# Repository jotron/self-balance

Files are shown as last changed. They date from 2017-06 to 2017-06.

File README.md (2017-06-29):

# Selbst-Balancierender Roboter

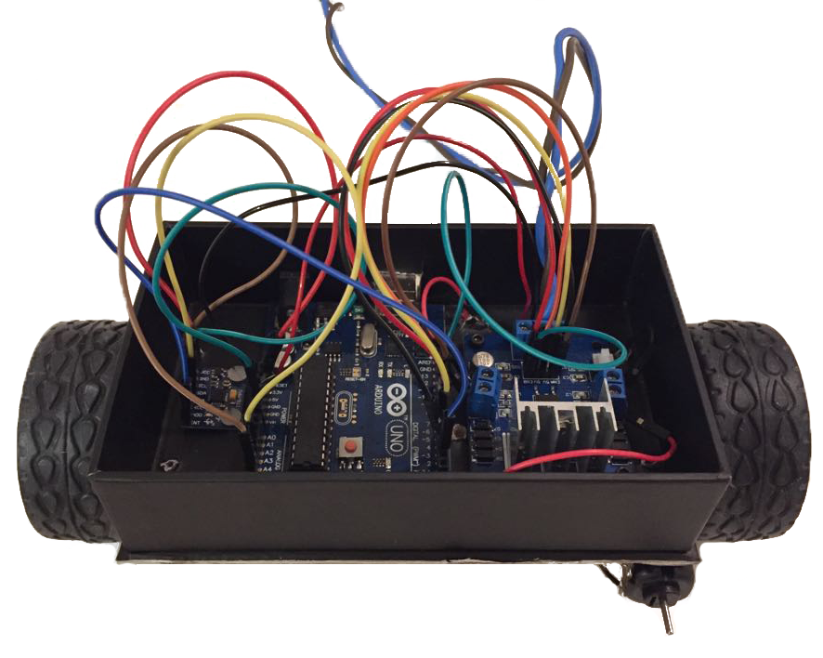
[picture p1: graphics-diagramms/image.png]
Robot


### Ziel

Ziel ist es einen Roboter mit 2-Rädern zu bauen, der von selbst gerade stehen kann in dem er sich ausbalanciert.

Mit einem Sensor soll der Roboter die Abneigung zur Senkrecht-Achse messen. Daraus folgend soll er die Motoren in die richtige Richtung stark genug antreiben.

balancing

### Bauteile

- Arduino Uno
- L298N Motor Driver Board Dual H-Bridge ([OEM](http://www.play-zone.ch/de/l298n-motor-driver-board-schrittmotor-treiber-modul-1550.html))
- MPU-6050 Gyroskop + Accelerometer ([Invensense](http://www.play-zone.ch/de/mpu-6050-accelerometer-gyro.html))
- 2 DC-Motoren (mit Getriebe)

### Schaltskizze

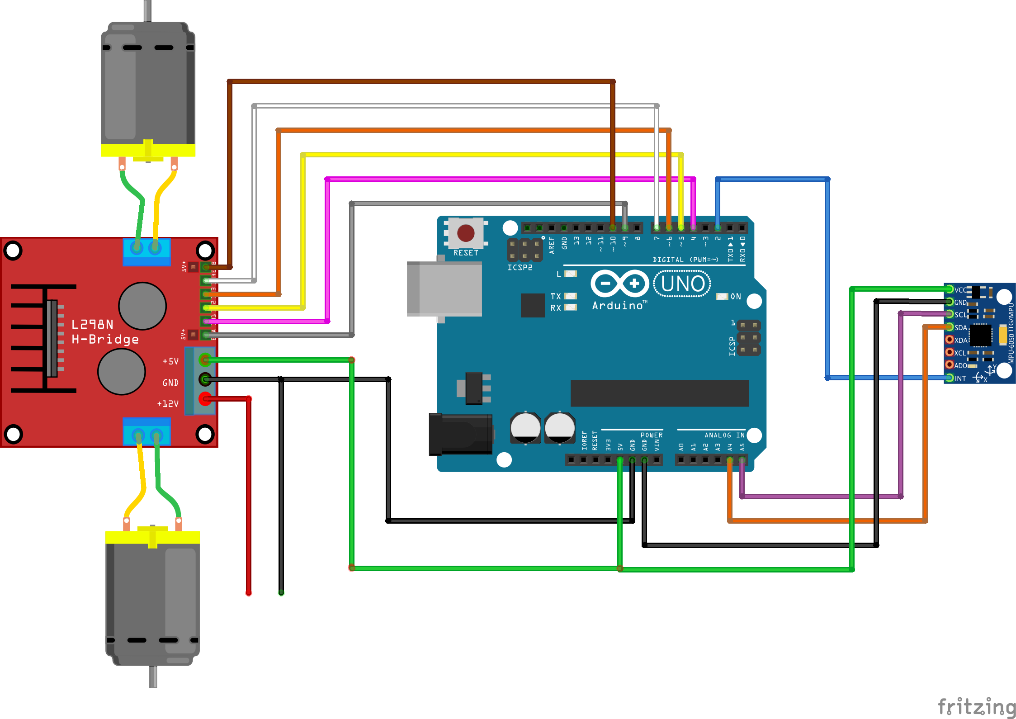
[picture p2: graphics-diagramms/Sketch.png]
Sketch


### Libraries 

- [PID](https://github.com/br3ttb/Arduino-PID-Library/)
- [I2Cdev](https://github.com/jrowberg/i2cdevlib)
- [MPU6050](https://github.com/jrowberg/i2cdevlib/tree/master/Arduino/MPU6050)
- Wire

### Arbeitsvorgang

1. [MPU-6050 Sensordaten ablesen](individual_files/mpu6050/MPU6050.md)
2. [Motoren ansteuern](individual_files/l298n/l298n.md)
3. [Steuerung von Motoren in Abhängigkeit der Neigung (PID)](individual_files/PID/PID.md)

### Fazit

[Kleines Video](graphics-diagramms/IMG_3839.mp4)

Das Projekt hatte sehr hohe Ansprüche. Schlussendlich sind wir mit der Realisation unseres Projekts zufrieden. Der Roboter balanciert zwar nicht stabil aber theoretisch haben wir alles richtig gemacht. Wir wissen noch nicht ob der Fehler technischer Natur ist oder aufgrund der Steuerung. 
Einerseits könnte das Problem daran liegen, dass unsere Motoren zu langsam reagieren, da bei jedem Richtungswechsel die Trägheit überwunden werden muss.  
Andernseits  könnte es daran liegen, dass wir einfach noch nicht die richtigen Parameter für den PID-Controller gefunden haben.
Schlussendlich ist es auch möglich, dass der niedrige Aufbau das Problem ist. Die Motoren müssen nämlich innerhalb von wenigen Milisekunden unter den fallenden Überbau fahren, was vielleicht zu schnell ist.

Das Schöne an diesem Projekt für uns ist eigentlich die lehrreiche Erfahrung. Wir haben sehr viel gelernt über einzelne Bauteile bis zu wie man ein solches Elektronik-Projekt angeht und wo eventuell Schwierigkeiten auftreten können.

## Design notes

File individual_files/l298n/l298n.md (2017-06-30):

## L298N H-Brücke

Der zweite Schritt bestand darin die Motoren mit der H-Brücke zu verkabeln und diese zur externen Stomquelle und zum Arduino. Das Wissen dazu haben wir aus diesen drei Tutorials erlernt: [Dronebotworkshop](http://dronebotworkshop.com/dc-motors-l298n-h-bridge/), [QQtrading](http://qqtrading.com.my/stepper-motor-driver-module-L298N), [Robotoid](http://www.robotoid.com/appnotes/circuits-l298-hbridge.html).

### Funktionsweise

#### Einfache H-Brücke

Prinzipschaltbild Motorsteuerung: H-Bridge mit vier Schaltern, der Motor vervollständigt das 'H'

Man kann sich eine H-Brücke der Einfachheit als 4 Schalter vorstellen. Werden in der Abbildung *Schalter 1* und *Schalter 4* aktiviert, dreht der Motor in eine Richtung. Werden hingegen *Schalter 3* und *Schalter 2* aktiviert drehr der Motor logischerweise in die andere Richtung. 
Auf unserem Chip besteht die H-Brücke allerdings nicht aus Schaltern sondern Transitoren.
Wird Spannung auf dem ersten und vierten Transistor aufgelegt fliesst der Strom und der Motor dreht. Analog dreht der Motor in die andere Richtung falls Transistor zwei und drei unter Spannung stehen.



#### L298N Doppelte H-Brücke

Der Chip den wir benutzen ist allerdings noch komplexer. Er besteht nämlich aus zwei H-Brücken und einem 5V Regulator. 
Im obereren Teil der Grafik sind alle Pins  sowie ihre Funktion gekennzeichnet in einer Schaltskizze.
Im unteren Teil der Grafik sieht man was sonst noch alles auf dem Chip ist. Man erkennt zum Beispiel im Rechten Teil die Dioden und links Oben den 5V-Regulator.



Die Motoren lassen sich je über 3 Pins ansteuern. Für den Motor A sind es die Pins IN1, IN2 sowie EnableA. Für den Motor B die pins IN3, IN4 und EnableB. Die IN Pins kontrollieren die Richtung des Stroms und somit die Richtung der Motoren.

| IN1  | IN2  | A Motorbewegung |
| ---- | ---- | --- |
| LOW  | LOW  | nichts |
| HIGH | LOW  | vorwärts |
| LOW  | HIGH | rückwärts |
| HIGH | HIGH | festhalten |

Die *Enable* Pins kontrollieren die Spannung über PWM und somit die Geschwindigkeit des jeweiligen Motors.

### Stromzufuhr

Eine Schwierigkeit bestand darin wie man den Strom zuführen sollte. Wir wollten nämlich auf zwei verschiedene Stromquellen verzichten. Schlussendlich haben wir uns entschieden den Arduino über die H-Brücke zu füttern und diese über ein 12V Netzkabel. Die H-Brücke besitzt nämlich einen 5V-Regulator. Das einzige Risiko dabei war, dass die Motoren eventuell zu viel elektrischen Lärm machen würden. Dies hat sich aber nicht bestätigt.

### Mini-Schaltskizze

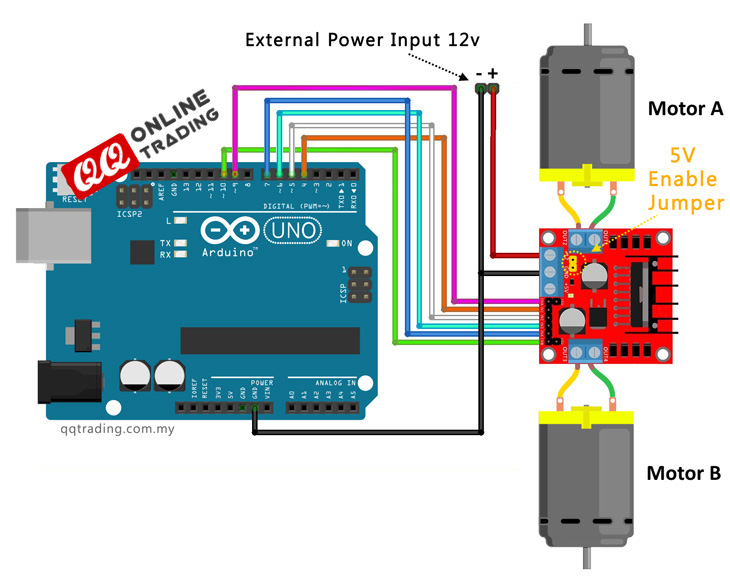
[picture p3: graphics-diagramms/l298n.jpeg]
l298n


### Code

```C
// PINS definieren Motor A
int IN1 = 4;
int IN2 = 5;
int speedPinA = 9; // PWM

// PINS definieren Motor B
int IN3 = 6;
int IN4 = 7;
int speedPinB = 10; // PWM

void setup()
{
 // Ausgabe PINS
 pinMode(IN1, OUTPUT);
 pinMode(IN2, OUTPUT);
 pinMode(IN3, OUTPUT);
 pinMode(IN4, OUTPUT);
 pinMode(speedPinA,OUTPUT);
 pinMode(speedPinB,OUTPUT);
}

void loop() {
  
 analogWrite(speedPinA, 50); // Geschwindigkeit einstellen 0-255
 analogWrite(speedPinB, 50); 

 // Motor A forwaerts
 digitalWrite(IN1, HIGH);
 digitalWrite(IN2, LOW);
 delay(2000);
 
 // Motor A rueckwaerts
 // digitalWrite(IN1, LOW);
 // digitalWrite(IN2, HIGH);
 // delay(2000);

 // Motor A deaktivieren
 // digitalWrite(IN1, LOW);
 // digitalWrite(IN2, LOW);
 // delay(2000);

 // Motor B forwaerts
 digitalWrite(IN3, HIGH);
 digitalWrite(IN4, LOW);
 delay(2000);
 
 // Motor B rueckwaerts
 // digitalWrite(IN3, LOW);
 // digitalWrite(IN4, HIGH);
 // delay(2000);

 // Motor B deaktivieren
 // digitalWrite(IN3, LOW);
 // digitalWrite(IN4, LOW);
 // delay(2000);
}
```

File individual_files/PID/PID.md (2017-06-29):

## Steuerung in Abhängigkeit der Neigung mittels PID

Es musste ein System entwickelt werden welches je nach Neigung des Roboters, die Motoren richtig ansteuerte. Dies erwies sich als ausserordentlich schwierig. Die intuitive Version einfach je nach Neigung mit voller Kraft in die richtige Richtung anzutreiben funktioniert nicht.
Wir haben darum eine Bibliothek gefunden die uns diese Aufgabe erleichtert: die [PID Bibliothek](https://playground.arduino.cc/Code/PIDLibrary).

Wikipedia: "Der [PID-Regler](https://de.wikipedia.org/wiki/Regler#PID-Regler) (proportional–integral–derivative controller) besteht aus den Anteilen des Proportionalen Gliedes, des Integral-Gliedes und des Derivativ-Gliedes." Die Bibliothek vergleicht den Input-Wert mit dem gewünschten Output-Wert und versucht den Stellwert optimal zu erreichen.
Man muss dem Regler lediglich einen Input vorschreiben und das gewünschte Resultat einstellen. Der Regler berechnet dann den Weg der minimalen Abweichung. Wie genau die Formel lautet die der Regler verwendet besprechen wir in dieser Arbeit nicht. Der Wikipedia Artikel wird nämlich ziemlich schnell recht komplex.

Der P-Wert steuert dabei wie stark der Roboter schwankt. Der I-Wert vermeidet "Overshoot" und treibt die Motoren gleichmässiger an. Der D-Wert korrigiert eventuelle Fehler.

### Code

Die Anpassungsparameter sind Kp, Ki & Kd.

```c
#include <PID_v1.h>

//Variablen und Parameter definieren
double pid_output = 0.0;
double pid_input = 255; // Neigung gegenüber Senkrecht-Achse
double setpoint = 255;
double Kp = 10;   //Schwankstärke
double Kd = 2; // beruhigen
double Ki = 0; // beruhigen

//PID aufstellen mit den Einstellungskonstanten und den INPUT/OUTPUT Variablen
PID pid(&pid_input, &pid_output, &setpoint, Kp, Ki, Kd, DIRECT);

void setup()
{
  //anschalten
  pid.SetMode(AUTOMATIC);
  
  //Alle 10ms neuberechnen
  pid.SetSampleTime(10);
}

void loop()
{
  //PID kontroller rechnen lassen, nur wenn 10ms vergangen sind, wird etwas passieren
  pid.Compute();
}
```

Der Regler schreibt automatisch in den pid_output. In unserem Programm bezeichnetein pid_input von 255 eine Neigung von 0° gegenüber der Senkrechtachse und ein pid_input von 0 einen +-90° Winkel. Die Richtung der Motoren wird separat manuell berechnet in abhängigkeit der Neigung.

Um auf die richtigen Konstanten zu kommen, benutzen wir die Ziegler-Nichols Methode:

1. Alle Werte auf 0 stellen
2. P so lang erhöhen bis der Roboter stark hin und her schwankt.
3. I so lang erhöhen bis der Roboter stabil steht
4. D experimentieren

Was uns gestört hat an der PID-Bibiothek ist, dass sie nicht selber die Richtung der Motoren kontrollieren kann. Wenn wir der Bibliothek nämlich Inputs von -255(rückwärts) bis +255(vorwärts) geben und der Roboter stabil steht, wird die Bibliothek den tiefsten Wert ausgeben -255 obwohl sie eigentlich 0 ausgeben sollte. 
An die richtigen Werte zu kommen ist ebenfalls sehr schwierig. Wir sind bis zum Abgabetermin noch auf keine funktionierenden Werte gekommen.

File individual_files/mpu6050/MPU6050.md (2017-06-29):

## MPU-6050

### Funktionsweise

#### Accelerometer
Der Accelerometer funktioniert auf Basis der [Piezoelektrizität](https://de.wikipedia.org/wiki/Piezoelektrizit%C3%A4t). Man kann sich eine kleine Box mit einer Kugel im inneren vorstellen. Jedes Mal wenn die Box in eine Richtung beschleuingt wird, stösst die Kugel an eine der 6 Wände aus Kristall. Bei diesem Stoss entsteht elektrische Ladung die gemessen werden kann.

Das Accelerometer misst also immer die totale wirkende Beschleunigung/Kraft.

Accelerometer

#### Gyroskop
Das Gyroskop funktioniert ähnlich dem Accelerometer mit Piezokristallen. Zusätzlich wird das Coriolis-Prinzip ausgenützt. Man kann sich eine Gabel-artige Struktur vorstellen die konstant hin und her schwingt. Wenn nun Bewegung Auftritt wirkt eine Kraft auf ein Ende der Gabel, was mit den Piezokristallen wiederum gemessen werden kann.
Das Gyroskop misst also nicht direkt die Neigung sondern nur die Änderung.

Gyroskop

### I2C

Als Kommunikationsprotokol mit dem Sensor vewenden wir *Inter-integrated Circuit*. Das Protokoll benötift zwei Verbindungen: *SCL* und *SDA*. *SCL* ist das Clock-Signal. Es ermörglicht synchronisierte Kommunikation.
*SDA* ist das Daten-Signal. Über dieses Kabel werden die Daten ausgetauscht.

Genauer als das haben wir das Protokoll nicht analysiert. Das ganze scheint recht komplex zu sein um es wirklich zu verstehen.

### Zusammenbau und Code

Als aller erstes haben wir den Sensor mit dem Arduino verbunden und die rohen Daten abgelesen. 

Fig (4) : CONNECTION DIAGRAM (tutorial 1) 

```c
int16_t ax, ay, az;
int16_t gx, gy, gz;

void setup() {
    // join I2C bus (I2Cdev library doesn't do this automatically)
    #if I2CDEV_IMPLEMENTATION == I2CDEV_ARDUINO_WIRE
        Wire.begin();
    #elif I2CDEV_IMPLEMENTATION == I2CDEV_BUILTIN_FASTWIRE
        Fastwire::setup(400, true);
    #endif

    // initialize serial communication
    // (38400 chosen because it works as well at 8MHz as it does at 16MHz, but
    // it's really up to you depending on your project)
    Serial.begin(9600);

    // initialize device
    Serial.println("Initializing I2C devices...");
    accelgyro.initialize();

    // verify connection
    Serial.println("Testing device connections...");
    Serial.println(accelgyro.testConnection() ? "MPU6050 connection successful" : "MPU6050 	   connection failed");

    accelgyro.setXGyroOffset(220);
    accelgyro.setYGyroOffset(76);
    accelgyro.setZGyroOffset(-85);
}

void loop() {
	accelgyro.getMotion6(&ax, &ay, &az, &gx, &gy, &gz);
}
```

Dabei haben uns die [offzielle Arduino Dokumentation](https://playground.arduino.cc/Main/MPU-6050), [ein Tutorial](https://create.arduino.cc/projecthub/Aritro/getting-started-with-imu-6-dof-motion-sensor-96e066) sowie die Beispiele in der Bibiliothek geholfen. Den vollständigen, funktionierenden Beispiel-Code findet man [hier](https://raw.githubusercontent.com/jrowberg/i2cdevlib/master/Arduino/MPU6050/examples/MPU6050_raw/MPU6050_raw.ino).

Um aus den rohen Daten die Neigung zu bekommenhaben wir anfänglich die rohen Accelerometer und Gyroskop-Werte mittels [Komplementären-Filter](https://bayesianadventures.wordpress.com/2013/10/20/gyroscopes-accelerometers-and-the-complementary-filter/) kombiniert um den Winkel zur Senkrechtachse zu bekommen. 

```c
void loop() {
    // read raw accel/gyro measurements from device
    accelgyro.getMotion6(&ax, &ay, &az, &gx, &gy, &gz);

    // Convert accelerometer raw values to degrees
    accXangle = (atan2(ay, az) + PI) * RAD_TO_DEG;
    accYangle = (atan2(ax, az) + PI) * RAD_TO_DEG;

    //Gyroskop in grad/sec umwandeln
    gx_correct = gx / 131;
    gy_correct = gy / 131;
    gz_correct = gz / 131;

    // Komplämentärer Filter
    compAngleX = (0.98 * (compAngleX + (gx_correct * (double)(micros() - timer) / 1000000))) + (0.02 * accXangle);
    delta = 180-compAngleX;

    timer = micros();
}
```

Das hat zwar funktioniert war aber rechenaufwendig. Deshalb haben wir uns schlussendlich doch auf den *Digital Motion Processor* des Sensor's verlassen. Der Sensor kann nämlich die Daten selber schon auswerten und die Neigung zurückgeben. ([hilfreiches Beispiel-Programm](https://github.com/jrowberg/i2cdevlib/blob/master/Arduino/MPU6050/examples/MPU6050_DMP6/MPU6050_DMP6.ino)).
Diese Methode ist allerdings komplizierter da der Buffer des Chips direkt abgelesen werden muss.

```c
void setup() {
    // join I2C bus (I2Cdev library doesn't do this automatically)
    #if I2CDEV_IMPLEMENTATION == I2CDEV_ARDUINO_WIRE
        Wire.begin();
        Wire.setClock(400000); // 400kHz I2C clock. Comment this line if having 			compilation difficulties
    #elif I2CDEV_IMPLEMENTATION == I2CDEV_BUILTIN_FASTWIRE
        Fastwire::setup(400, true);
    #endif

    // initialize serial communication
    Serial.begin(9600);
  
    // initialize device
    Serial.println(F("Initializing I2C devices..."));
    mpu.initialize();
    pinMode(INTERRUPT_PIN, INPUT);

    // verify connection
    Serial.println(mpu.testConnection() ? F("MPU6050 connection successful") : F("MPU6050 	  connection failed"));

    // load and configure the DMP
    devStatus = mpu.dmpInitialize();

    // supply your own gyro offsets here, scaled for min sensitivity
    mpu.setXGyroOffset(220);
    mpu.setYGyroOffset(76);
    mpu.setZGyroOffset(-85);
    mpu.setZAccelOffset(1788); // 1688 factory default for my test chip

    // make sure it worked (returns 0 if so)
    if (devStatus == 0) {
        // turn on the DMP, now that it's ready
        Serial.println(F("Enabling DMP..."));
        mpu.setDMPEnabled(true);

        // enable Arduino interrupt detection
        Serial.println(F("Enabling interrupt detection (Arduino external interrupt 				0)..."));
        attachInterrupt(digitalPinToInterrupt(INTERRUPT_PIN), dmpDataReady, RISING);
        mpuIntStatus = mpu.getIntStatus();

        // set our DMP Ready flag so the main loop() function knows it's okay to use it
        Serial.println(F("DMP ready! Waiting for first interrupt..."));
        dmpReady = true;

        // get expected DMP packet size for later comparison
        packetSize = mpu.dmpGetFIFOPacketSize();
    } else {
        // ERROR!
        // 1 = initial memory load failed
        // 2 = DMP configuration updates failed
        // (if it's going to break, usually the code will be 1)
        Serial.print(F("DMP Initialization failed (code "));
        Serial.print(devStatus);
        Serial.println(F(")"));
    }
}

void loop() {
    // if programming failed, don't try to do anything
    if (!dmpReady) return;

    // wait for MPU interrupt or extra packet(s) available
    while (!mpuInterrupt && fifoCount < packetSize) {
        // other program behavior stuff here
    }

    // reset interrupt flag and get INT_STATUS byte
    mpuInterrupt = false;
    mpuIntStatus = mpu.getIntStatus();

    // get current FIFO count
    fifoCount = mpu.getFIFOCount();

    // check for overflow (this should never happen unless our code is too inefficient)
    if ((mpuIntStatus & 0x10) || fifoCount == 1024) {
        // reset so we can continue cleanly
        mpu.resetFIFO();
        Serial.println(F("FIFO overflow!"));

    // otherwise, check for DMP data ready interrupt (this should happen frequently)
    } else if (mpuIntStatus & 0x02) {
        // wait for correct available data length, should be a VERY short wait
        while (fifoCount < packetSize) fifoCount = mpu.getFIFOCount();

        // read a packet from FIFO
        mpu.getFIFOBytes(fifoBuffer, packetSize);
        
        // track FIFO count here in case there is > 1 packet available
        // (this lets us immediately read more without waiting for an interrupt)
        fifoCount -= packetSize;

        mpu.dmpGetQuaternion(&q, fifoBuffer);
        mpu.dmpGetGravity(&gravity, &q);
        mpu.dmpGetYawPitchRoll(ypr, &q, &gravity);
        Serial.print("ypr\t");
        Serial.print(ypr[0] * 180/M_PI);
        Serial.print("\t");
        Serial.print(ypr[1] * 180/M_PI);
        Serial.print("\t");
        Serial.println(ypr[2] * 180/M_PI);
    }
}
```

Um die Präzision zu erhöhen mussten wir die Sensor-spezifische Fehlabneigungen (offset) berechnen. Dazu geholfen hat uns das [Skript](http://wired.chillibasket.com/2015/01/calibrating-mpu6050/) von *Luis Ródenas*.

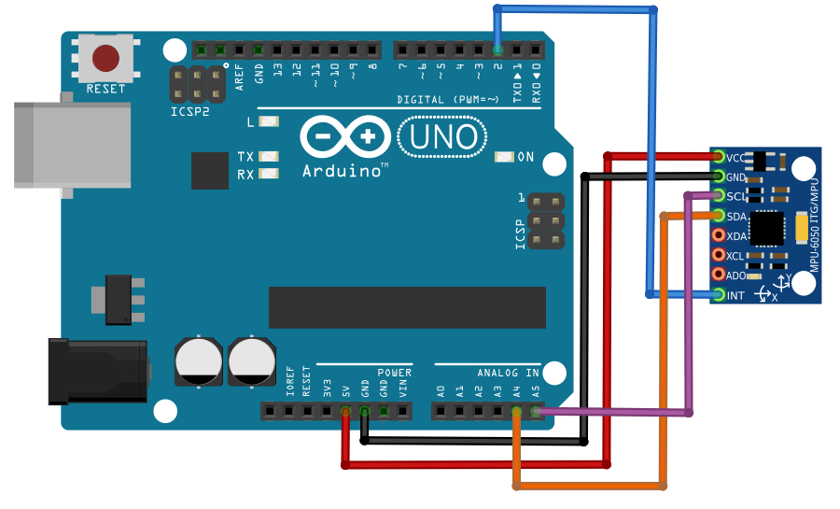
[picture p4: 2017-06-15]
graphics-diagramms/mpu6050.png

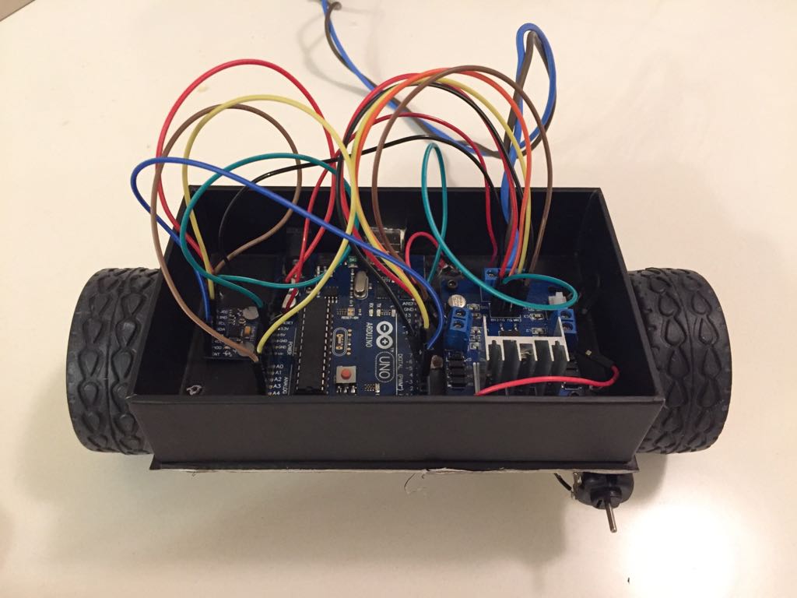
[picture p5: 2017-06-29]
graphics-diagramms/image.jpeg

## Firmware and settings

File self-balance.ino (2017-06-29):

// Alle Bibliotheken muessen installiert sein.
#include "PID_v1.h"
#include "I2Cdev.h"
#include "MPU6050_6Axis_MotionApps20.h"
// Wire-Library nur in gewissen Faellen benoetigt
#if I2CDEV_IMPLEMENTATION == I2CDEV_ARDUINO_WIRE
    #include "Wire.h"
#endif

//Gyroskop-Accelerometer initialisieren
MPU6050 mpu;

// Variablen definieren MPU
bool dmpReady = false;  // wird auf True gesetzt falls Verbindung erfolgreich
uint8_t mpuIntStatus;   // holds actual interrupt status byte from MPU
uint8_t devStatus;      // return status after each device operation (0 = success, !0 = error)
uint16_t packetSize;    // expected DMP packet size (default is 42 bytes)
uint16_t fifoCount;     // count of all bytes currently in FIFO
uint8_t fifoBuffer[64]; // FIFO storage buffer

Quaternion q;           // [w, x, y, z]         quaternion container
VectorFloat gravity;    // [x, y, z]            gravity vector
float ypr[3];           // [yaw, pitch, roll]   yaw/pitch/roll container and gravity vector

// Input Motor A
int IN1 = 4;
int IN2 = 5;
int speedPinA = 9;

// Input Motor B
int IN3 = 6;
int IN4 = 7;
int speedPinB = 10;

// PID variablen definieren
/* Der Sensor misst den Winkel von -180 bis + 180
 * Wir erweitern den Betrag davon auf 255 und setzen 255 als 0° und Zielpunkt für das PID 
 * Der PID gibt, dann wiederum einen Output von 0 bis 255 (225) mit dem man direkt
 * die Motoren ansteuern kann über PWM
*/
double delta; // eigentliche Winkel gegenüber Senkrecht-Achse
double pid_output = 0.0;
double pid_input = 225; // Winkel gegenüber Senkrecht-Achse erweitert
double setpoint = 225; // Zielwert fuer PID-Controller
double Kp = 0.6;   //Proportional (Schwankstärke)
double Ki = 0.01;  // beruhigen
double Kd = 0; // beruhigen

// PID initialisieren
PID pid(&pid_input, &pid_output, &setpoint, Kp, Ki, Kd, DIRECT);

// Testet Unterbrechung mit MPU
volatile bool mpuInterrupt = false;
// indicates whether MPU interrupt pin has gone high
void dmpDataReady() {
    mpuInterrupt = true;
}

// ================================================================
// ===                      INITIAL SETUP                       ===
// ================================================================
void mpu_init() {
    // I2C Verbindung initialisieren
    #if I2CDEV_IMPLEMENTATION == I2CDEV_ARDUINO_WIRE
        Wire.begin();
        TWBR = 24; // 400kHz I2C clock (200kHz if CPU is 8MHz)
    #elif I2CDEV_IMPLEMENTATION == I2CDEV_BUILTIN_FASTWIRE
        Fastwire::setup(400, true);
    #endif

    // Serielle Kommunikation initialisieren sowie MPU initialisieren
    Serial.begin(9600);
    Serial.println(F("Initializing I2C devices..."));
    mpu.initialize();

    // Verbindung testen
    Serial.println(F("Testing device connections..."));
    Serial.println(mpu.testConnection() ? F("MPU6050 connection successful") : F("MPU6050 connection failed"));

    // DMP initialisieren
    Serial.println(F("Initializing DMP..."));
    devStatus = mpu.dmpInitialize();

    // Unsere eigenen gemessenen Offsets
    mpu.setXGyroOffset(41);
    mpu.setYGyroOffset(-92);
    mpu.setZGyroOffset(-23);
    mpu.setXAccelOffset(-1659);
    mpu.setYAccelOffset(-329);
    mpu.setZAccelOffset(1230);

    //Falls erfolgreich verbunden DMP gestartet
    if (devStatus == 0) {
        // DMP anstellen
        Serial.println(F("Enabling DMP..."));
        mpu.setDMPEnabled(true);

        // Unterbruch-Routine aktivieren
        Serial.println(F("Enabling interrupt detection (Arduino external interrupt 0)..."));
        attachInterrupt(0, dmpDataReady, RISING);
        mpuIntStatus = mpu.getIntStatus();

        // dmpReady auf true setzen, damit der Main loop starten kann
        Serial.println(F("DMP ready! Waiting for first interrupt..."));
        dmpReady = true;

        // erwartete Packetgroesse bekommen fuer spaeteren Vergleich
        packetSize = mpu.dmpGetFIFOPacketSize();
    } else {
        // ERROR!
        // 1 = initial memory load failed
        // 2 = DMP configuration updates failed
        // (if it's going to break, usually the code will be 1)
        Serial.print(F("DMP Initialization failed (code "));
        Serial.print(devStatus);
        Serial.println(F(")"));
    }

}
void setup() {

    //Accelereometer-Gyroskop initialisieren
    mpu_init();


    // L298N Pins
    pinMode(IN1, OUTPUT);
    pinMode(IN2, OUTPUT);
    pinMode(IN3, OUTPUT);
    pinMode(IN4, OUTPUT);
    pinMode(speedPinA,OUTPUT);
    pinMode(speedPinB,OUTPUT);

    //Setup PID
    pid.SetMode(AUTOMATIC); // PID aktivieren
    pid.SetSampleTime(10); // PID nur alle 10ms neu berechnen
    pid.SetOutputLimits(0, 225); // von 0 bis 225 weil + 30 MotorenTraegheit
}

// ================================================================
// ===                         CORE                             ===
// ================================================================
void motors() {
  // Falls Winkel positiv, Motoren in die richtige Richtung antreiben
  if (delta > 0) {
        digitalWrite(IN1, HIGH);
        digitalWrite(IN2, LOW);

        digitalWrite(IN3, HIGH);
        digitalWrite(IN4, LOW);
  }
  // Falls Winkel negativ, Motoren in die andere Richtung antreiben
  else {
        digitalWrite(IN1, LOW);
        digitalWrite(IN2, HIGH);
  
        digitalWrite(IN3, LOW);
        digitalWrite(IN4, HIGH);
   }
   
   // aktivieren für die PID kontrollierte Version
   analogWrite(speedPinA, pid_output + 20); // Geschwindigkeit einstellen
   analogWrite(speedPinB, pid_output + 20);

   // aktivieren für die Brute-Force Version
   //analogWrite(speedPinA, abs(delta) * 20 - 7);
   // analogWrite(speedPinB, abs(delta) * 20 + 7);
}
void mpu_get() {
  // Falls Programm gescheitert hat oder noch nicht bereit ist, nichts tun
    if (!dmpReady) return;

    // warten auf MPU-Signal
    while (!mpuInterrupt && fifoCount < packetSize) {
      //
    }

    // mpuInterrupt wieder auf false resetten und INT_STATUS empfangen
    mpuInterrupt = false;
    mpuIntStatus = mpu.getIntStatus();

    // Aktuellen FIFOBUFFER zaehlen
    fifoCount = mpu.getFIFOCount();

    // Overflow ueberpruefen und falls ja FIFO leeren
    if ((mpuIntStatus & 0x10) || fifoCount == 1024) {
        // reset so we can continue cleanly
        mpu.resetFIFO();
        Serial.println(F("FIFO overflow!"));

    // Sonst fuer Daten bereit zum ablesen testen
    } else if (mpuIntStatus & 0x02) {
        // Auf korrekte Paketlaenge warten
        while (fifoCount < packetSize) fifoCount = mpu.getFIFOCount();

        // Paket lesen
        mpu.getFIFOBytes(fifoBuffer, packetSize);

        // Falls mehr als ein Paket verfuegbar FIFO zaehlen
        fifoCount -= packetSize;

        // Eulerschen Winkel abfragen, berechnet vom interen Chip des Sensors
        mpu.dmpGetQuaternion(&q, fifoBuffer);
        mpu.dmpGetGravity(&gravity, &q);
        mpu.dmpGetYawPitchRoll(ypr, &q, &gravity);

        // Winkel in Grad abspeichern (-90 bis +90)
        delta = ypr[2] * 180/M_PI;
        // Winkel erweitern auf (0 bis 255) und umkehren (255 entspricht 0-Grad Winkel)
        pid_input = 225 - abs(ypr[2] * 180/M_PI) * 2.5;
    
    }
}
void loop() {
    mpu_get(); // Winkelmessung bekommen
    
    Serial.print("PID INPUT: " + String(pid_input));
    Serial.print(" PID OUTPUT: " + String(pid_output));
    Serial.println(" Winkel: " + String(delta));
    
    
    // aktivieren fuer die PID-Kontrollierte Version
    // wird eigentlich nur ausgefuehrt wenn 10ms vorbei sind
    pid.Compute(); // PID -Controller abfragen

    //L298N entsprechend steuern
    motors();

    //delay(10);
}

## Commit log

2017-06-17 Readme + theo. working
    [Sketch.fzz]
2017-06-17 V. 0.9
    - Sketch Correction
    - 1024 adapt inputs
    [Sketch.fzz]
2017-06-18 V 0.9.5
    - Working PID
2017-06-27 Adjusting Motors
2017-06-28 Nicer Print
2017-06-28 Motor polung
2017-06-29 Not working but ok
    [l298n.ino, self-balance.ino]
2017-06-29 PID experimenting
2017-06-29 Picture and Video
    [Sketch.fzz]
